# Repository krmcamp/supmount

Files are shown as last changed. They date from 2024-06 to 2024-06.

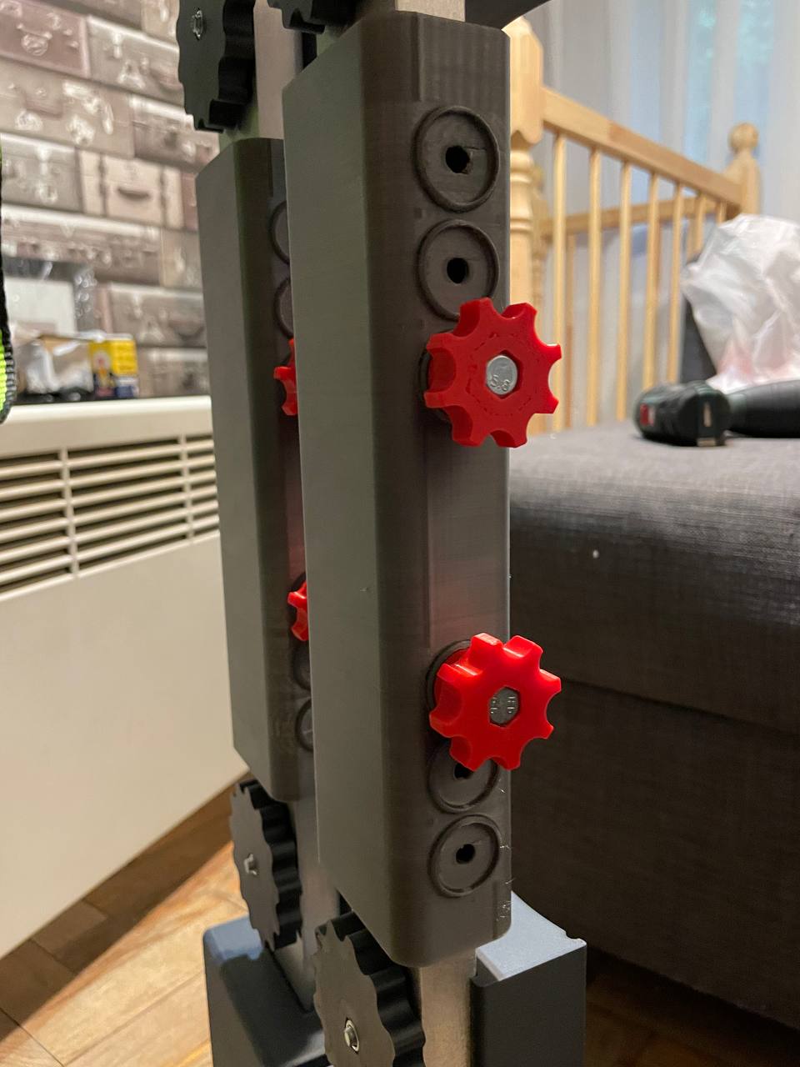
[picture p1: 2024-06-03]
fotp4.jpg

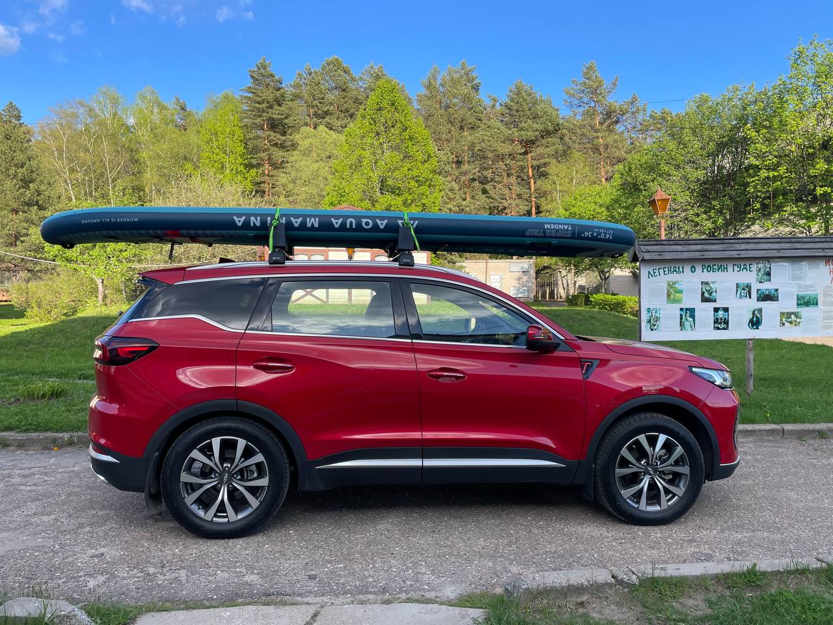
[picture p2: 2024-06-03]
foto2.jpg

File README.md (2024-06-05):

# supmount
Mounting the SUP board for the trunk to the roof of the car

The mounting supports were created for the Turtle Air 2 trunk, and may be suitable for other trunks.
Suitable for boards with a width of 86 and 81 cm wide. 
I drove Aqua Marina Super Trip Tandem 14'0" S24 (427 x 86 x 20 cm) and Aqua Marina Hyper 12'6" S23 (381 x 81 x 15 cm).

Aluminum profile was purchased in Leroy Merlin "Aluminum rectangular tubular profile 50x20x2x1000mm" LM 12362324
The shoulders, supports and large vents were printed by PLA carbon, but it is possible (necessary) from PETG.
A coupling made of PETG.
Small valves made of PLA

Fastening straps purchased in Leroy Merlin LM 89133474 "Standers fastening belt with buckle 25 mm x 2.75 m 2 pcs/pack."

Shoulder mounting bolts 8 pcs. (LM 13616883 Bolt with internal hexagon DIN 912 M6x30 mm, 4 pcs.)
Bolt for small valve coupling 4 pcs. (LM 10960830 Bolt M5x40 mm, 5 pcs.)
Thread was cut in profile.

Bolt for mounting supports in the T-slot of the trunk 4 pcs. (LM 10943774 DIN603 furniture bolt with nut 6x70 mm, chrome color, 6 pcs.)
Plate in the T-slot for reducing the area of the furniture bolt "Set of adapters for the aerodynamic arc of the T-slots (h-20mm) of the luggage system (8564)" Manufacturer Atlant. https://ozon.ru/t/MB4Zbag But you can make it yourself, it's just plates with a hole.

Nut in the large valve 4 pcs. (LM 10964479 Self-locking nut DIN 985 M6, 14 pcs.)

I printed the shoulders with a 30% filling, without supports. The walls, top and bottom are 8 layers.
The valves are 60% of the wall of 6 layers.
The coupling is 100%.

It took 4 coils of PLA Carbon, 2 coils of PETG.

-------------------RU---------------------

Крепление SUP доски для багажника на крышу машины

Опоры крепления создавались для багажника Turtle Air 2, возможно подойдут и для других багажников.
Подходит для досок шириной 86 и 81 см. шириной. 
Возил Aqua Marina Super Trip Tandem 14'0" S24 (427 х 86 х 20 см) и Aqua Marina Hyper 12'6" S23 (381 х 81 х 15 см).

Алюминевый профиль приобретал в Леруа Мерлен "Профиль алюминиевый прямоугольный трубчатый 50х20х2x1000 мм" ЛМ 12362324
Плечи, опоры и большие вентели печатал PLA carbon, но можно (нужно) из PETG.
Соеденительную муфту из PETG.
Малые вентили из PLA

Ремни крепления приобрета в Леруа Мерлен ЛМ 89133474 "Ремень Standers крепежный с пряжкой 25 мм х 2.75 м 2 шт./уп."

Болты крепления плечей 8 шт. (ЛМ 13616883 Болт с внутренним шестигранником DIN 912 M6х30 мм, 4 шт.)
Болт для малого вентиля муфты 4 шт. (ЛМ 10960830 Болт M5x40 мм, 5 шт.)
Резьба нарезалась в профиле.

Болт для крепления опор в Т-паз багажника 4 шт. (ЛМ 10943774 Болт мебельный DIN603 с гайкой 6х70 мм, цвет хром, 6 шт.)
Пластина в Т-паз для увиличения площади мебельного болта "Комплект переходников для аэродинамической дуги Т-слотов (h-20мм) багажной системы (8564)" Производитель Атлант. https://ozon.ru/t/MB4Zbag Но можно изготовить самому, это просто пластинки с отверстием.

Гайка в большого вентиля 4 шт. (ЛМ 10964479 Гайка самоконтрящаяся DIN 985 М6, 14 шт.)

Плечи печатал с заполнением 30%, без поддержек. Стенки, верх и низ 8 слоёв.
Вентили 60% стенки 6 слоёв.
Муфта 100%.

Ушло 4 катушки PLA Carbon, 2 катушки PETG.

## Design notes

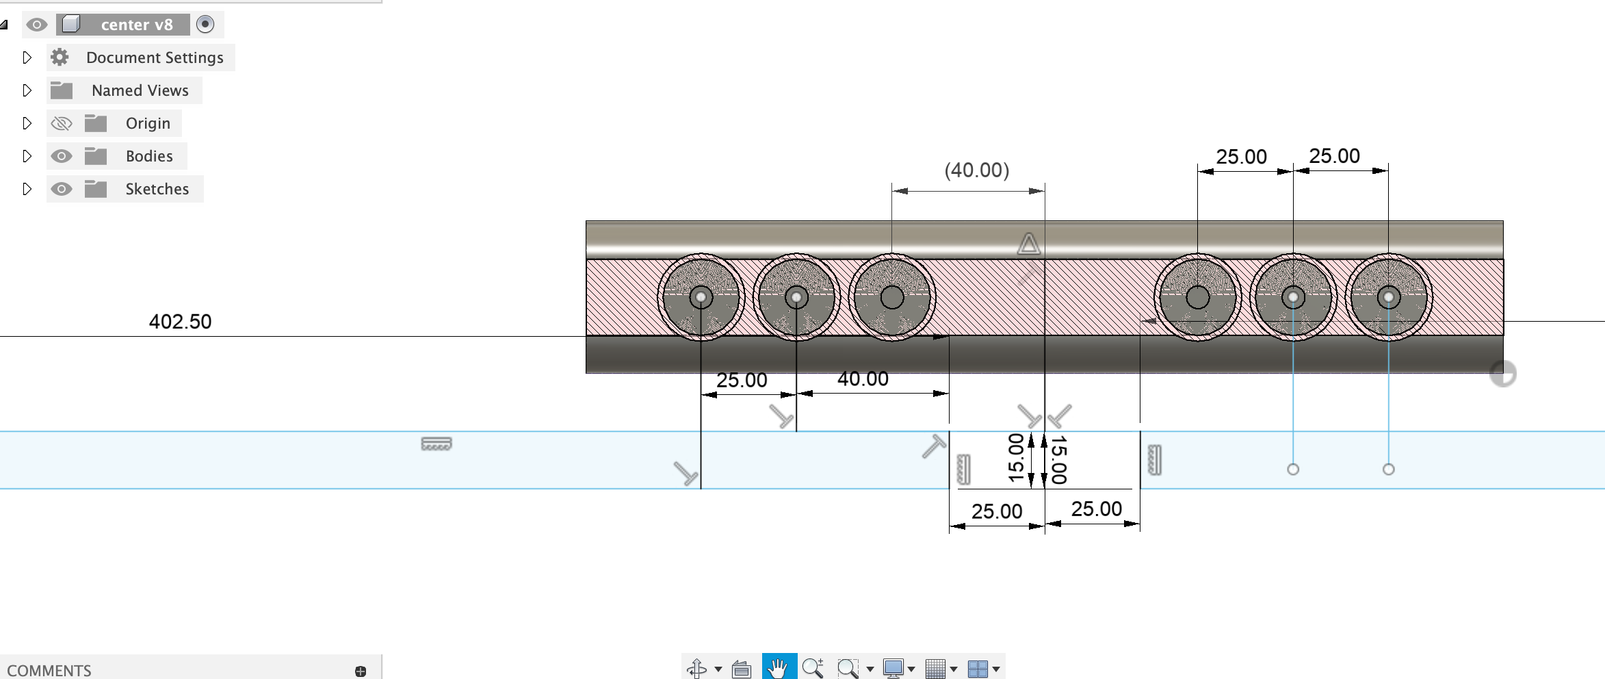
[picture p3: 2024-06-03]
razmeri.png

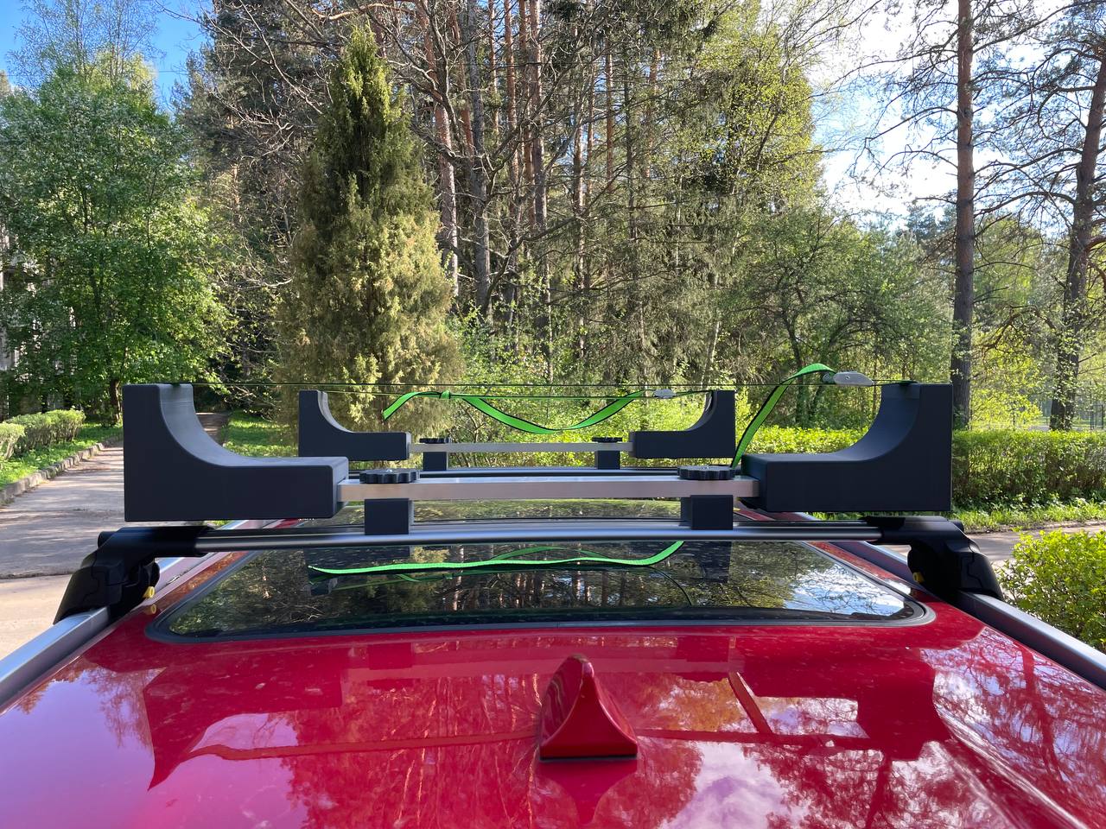
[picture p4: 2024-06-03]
foto1.jpg

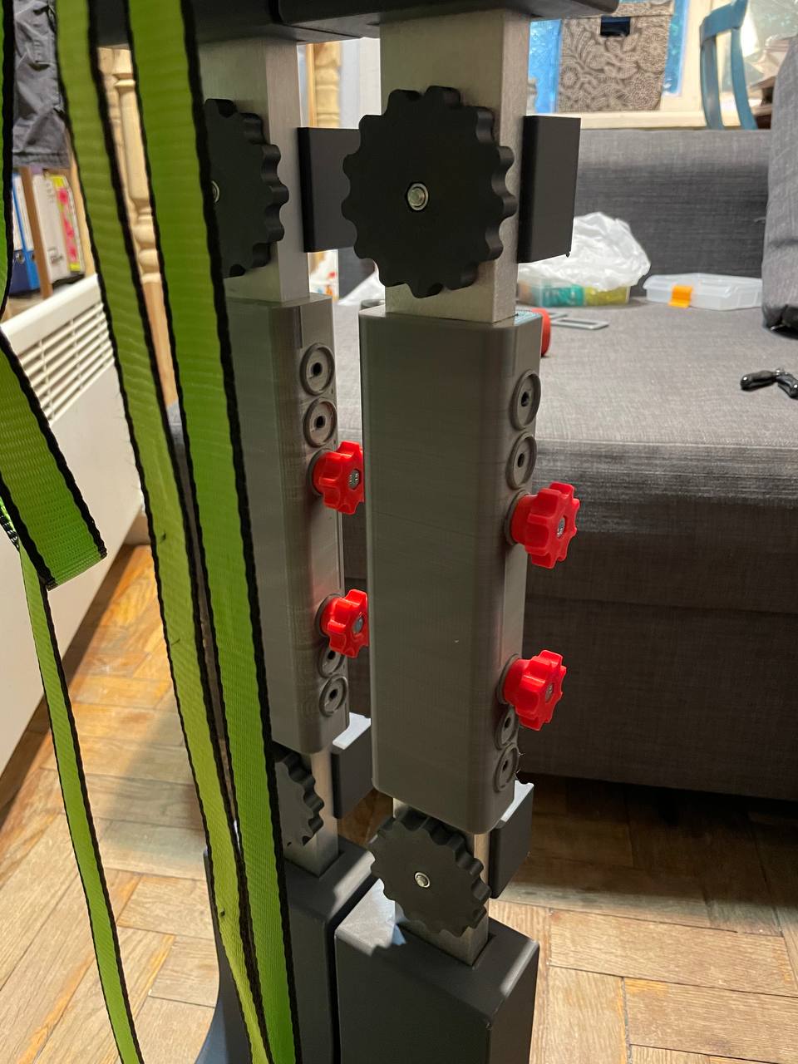
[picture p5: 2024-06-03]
foto3.jpg

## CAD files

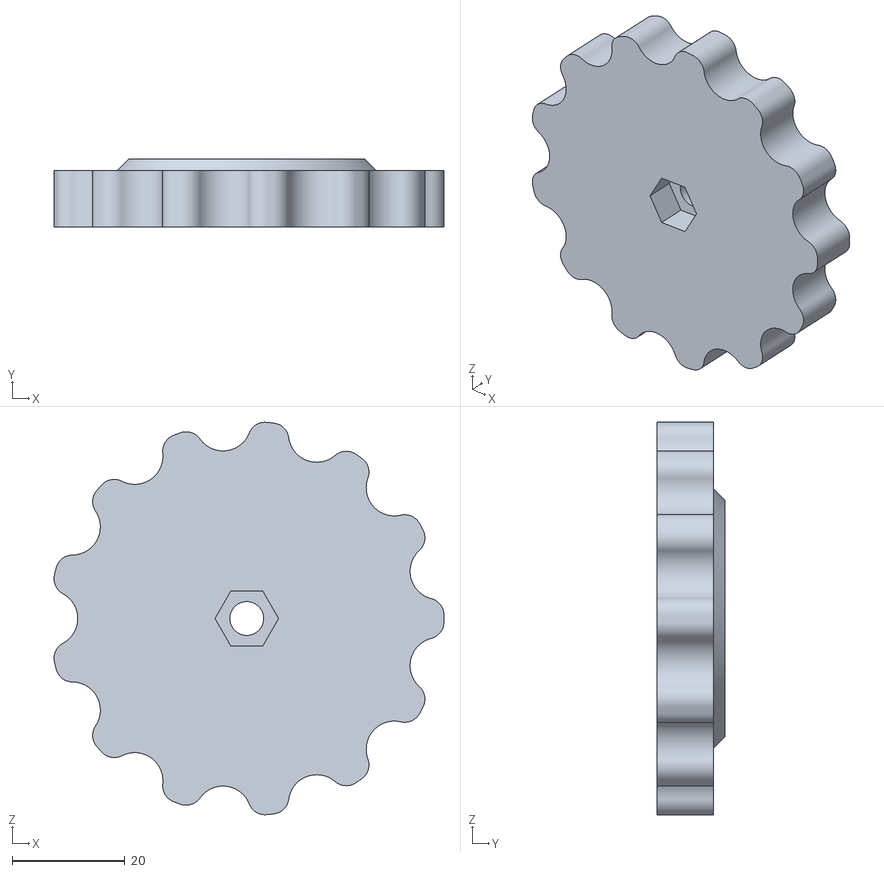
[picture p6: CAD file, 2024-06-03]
vent1.stl
69.2 x 12.0 x 69.7

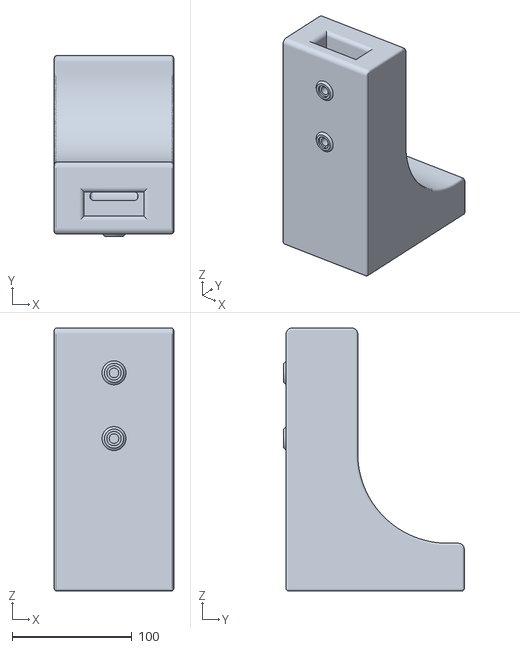
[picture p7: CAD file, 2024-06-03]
plecho.stl
100.0 x 151.1 x 220.0

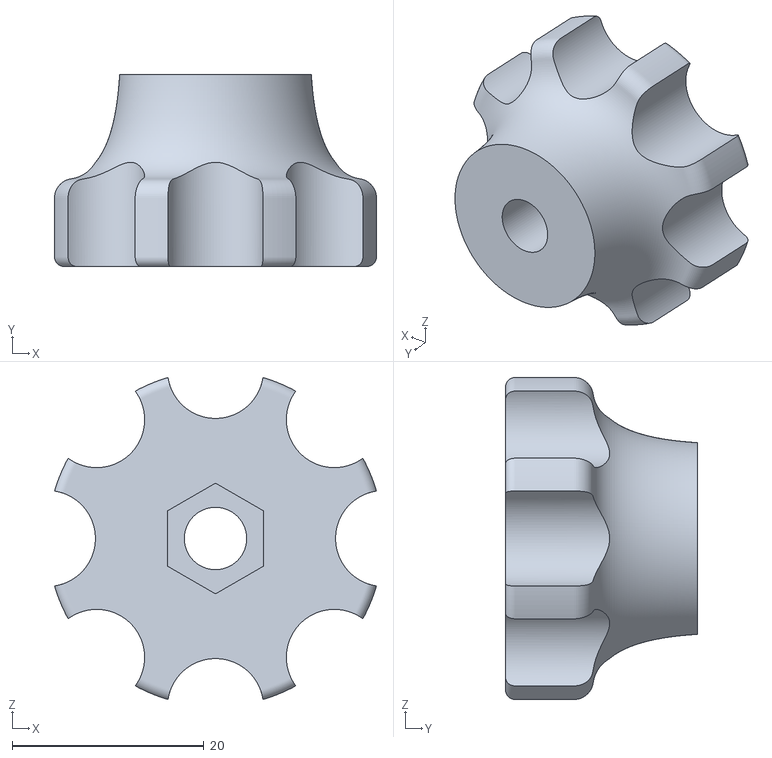
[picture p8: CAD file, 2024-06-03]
vent2.stl
33.6 x 20.0 x 33.6

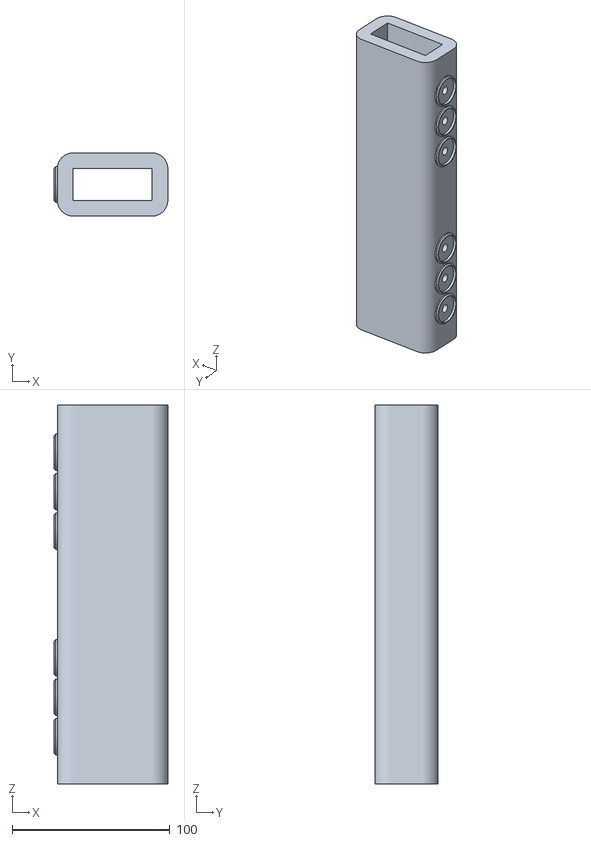
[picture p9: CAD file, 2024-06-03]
mufta.stl
72.0 x 40.0 x 240.0

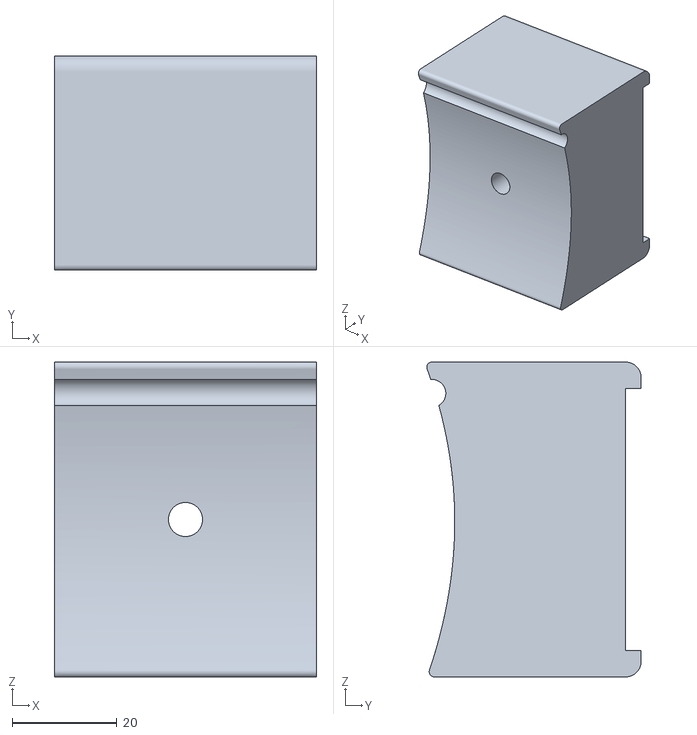
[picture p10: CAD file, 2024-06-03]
opora.stl
50.0 x 40.8 x 60.0
